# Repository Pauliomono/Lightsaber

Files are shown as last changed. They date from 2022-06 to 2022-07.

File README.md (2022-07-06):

# Lightsaber

DIY Lightsaber project completed over the summer of 2020.
 
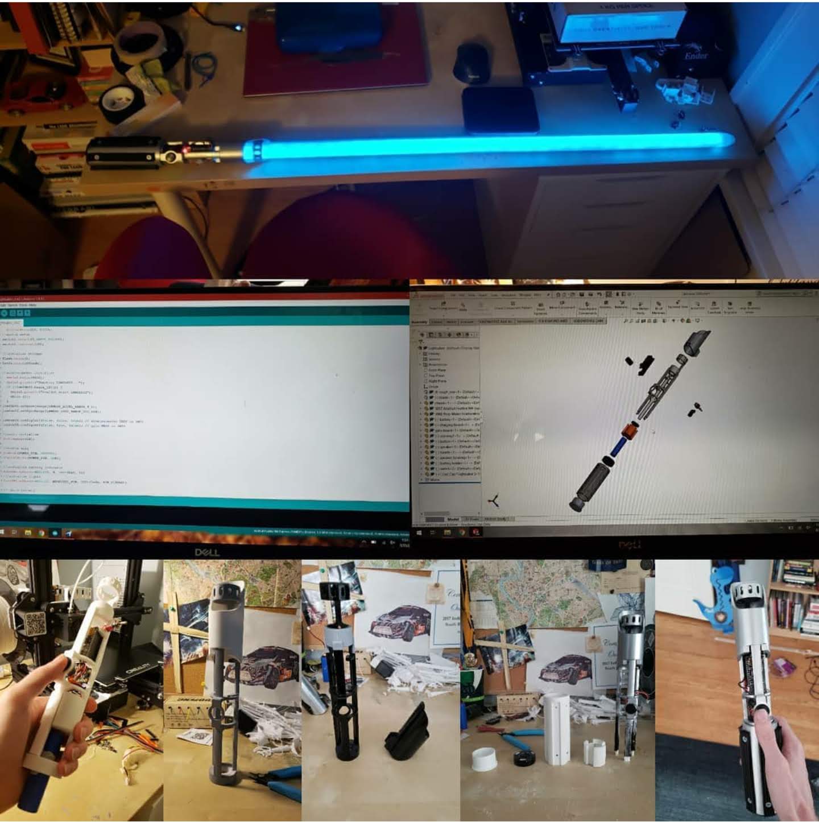
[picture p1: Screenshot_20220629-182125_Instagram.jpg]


Features include:

- Sound effects including on, off, and hit sounds
- Realistic lightsaber swing sounds mimic Doppler Effect
- LED blade with light animations for on/off sequences & reactions to hits

The entire handle is custom 3D printed and hand painted.

Electronics are handled by an Adafruit Feather M4 microcontroller with the Adafruit propshield. An MPU6050 is used for accelometer and gyroscope data. Lighting is achieved through a Neopixel strip. The lightsaber is powered by an 18650 lithium cell.

Future plans to fabricate a new handle out of aluminum and add more lighting functionality/animations.

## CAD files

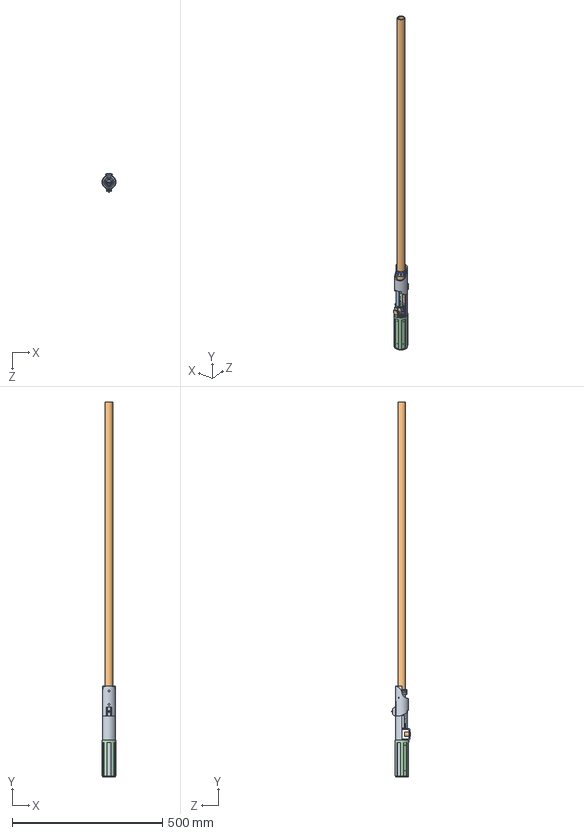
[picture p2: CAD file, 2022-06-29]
Lightsaber.SLDASM
46.7 x 1249.0 x 64.9 mm
chassis
3857 Adafruit Feather M4 Express
3988 Prop-Maker FeatherWing
battery
charging board
gyro board
opening1
button
speaker_housing
battery holder
switch
End_Cap^Lightsaber

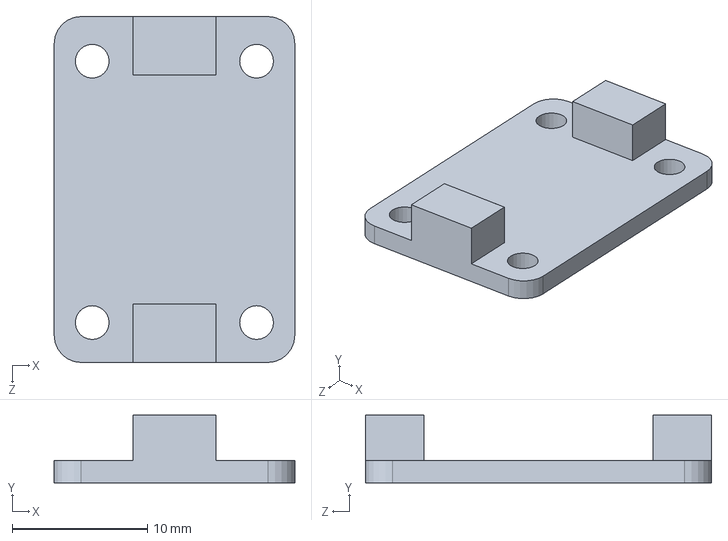
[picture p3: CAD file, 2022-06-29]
gyro board.SLDPRT
17.8 x 5.00 x 25.6 mm

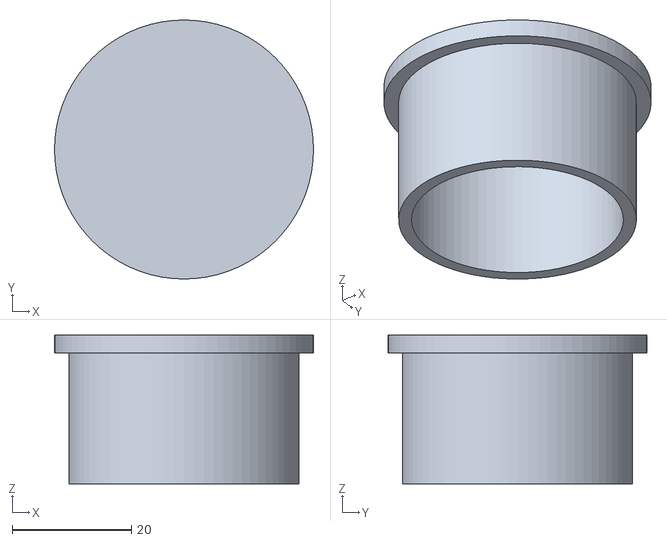
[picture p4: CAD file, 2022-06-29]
stls/End_Cap^Lightsaber.STL
43.5 x 43.5 x 25.0

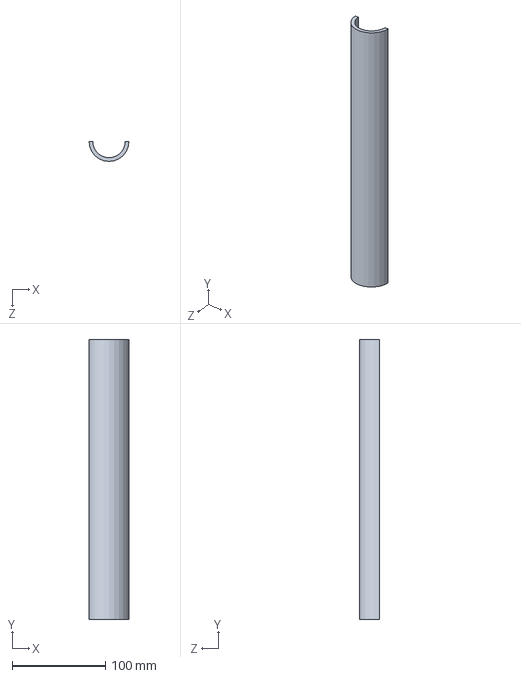
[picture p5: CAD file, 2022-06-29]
rough_size.SLDPRT
42.7 x 300.0 x 21.4 mm

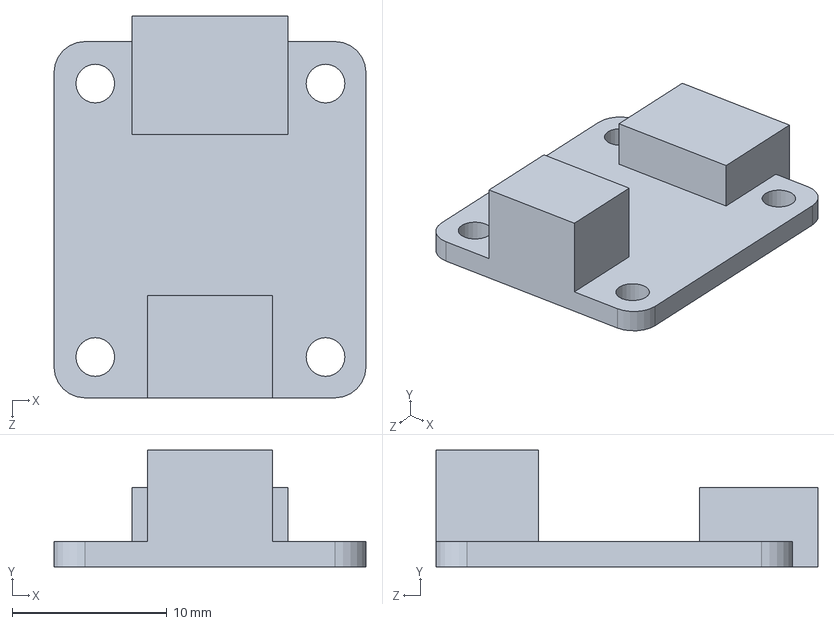
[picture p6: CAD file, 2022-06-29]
charging board.SLDPRT
20.1 x 7.55 x 24.6 mm

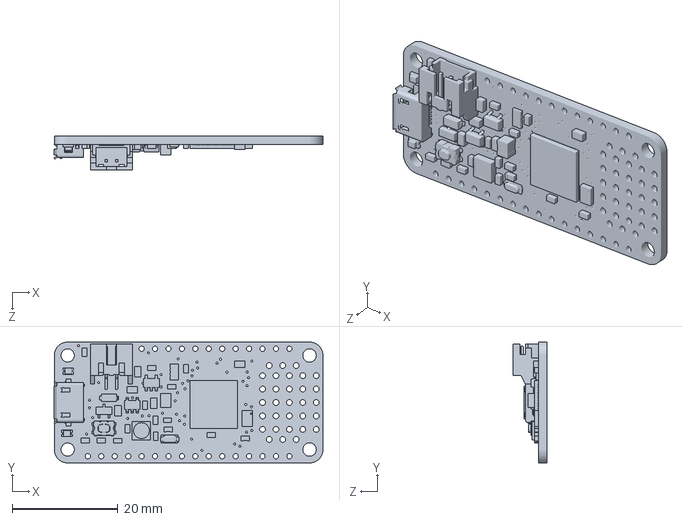
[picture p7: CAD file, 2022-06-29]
3857 Adafruit Feather M4 Express.SLDPRT
50.9 x 22.9 x 6.37 mm

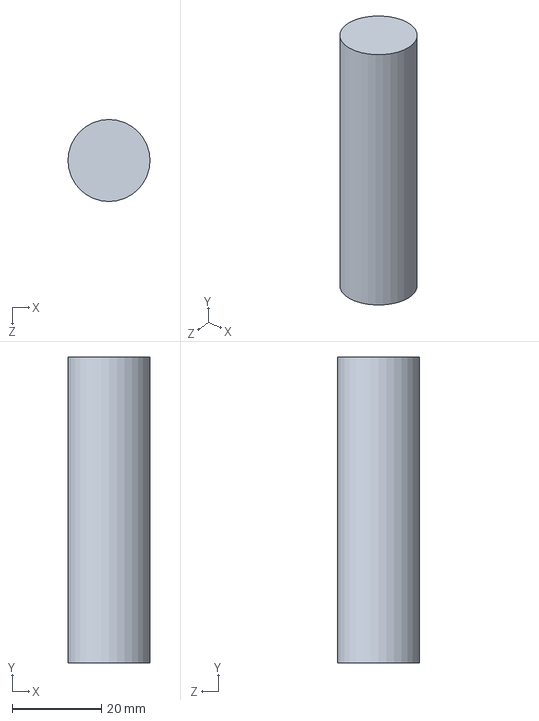
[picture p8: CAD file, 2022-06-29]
battery.SLDPRT
18.4 x 68.7 x 18.4 mm

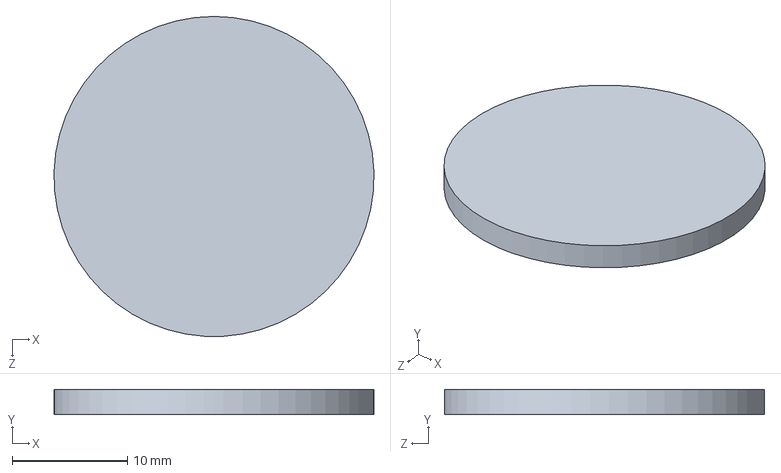
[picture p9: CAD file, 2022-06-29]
speaker.SLDPRT
27.8 x 2.20 x 27.8 mm

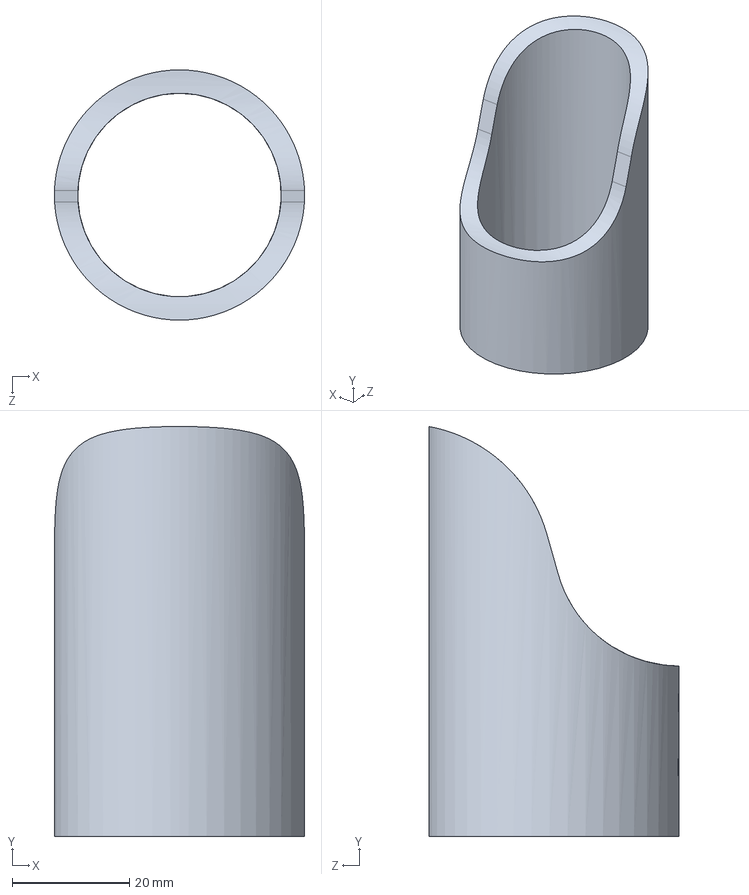
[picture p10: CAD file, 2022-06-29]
opening1.SLDPRT
42.7 x 70.0 x 42.7 mm

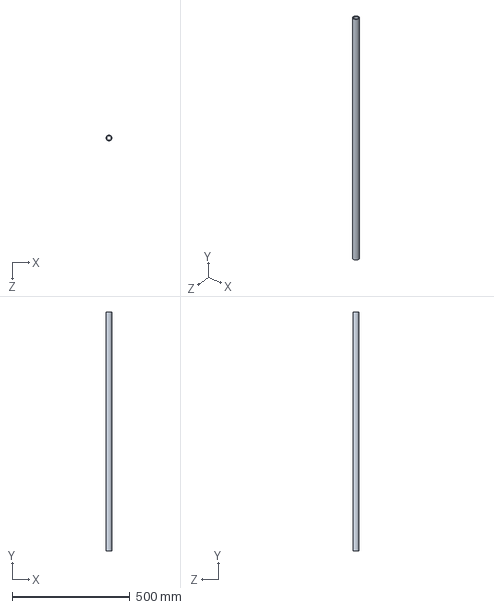
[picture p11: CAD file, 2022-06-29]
blade.SLDPRT
25.4 x 1016.0 x 25.4 mm

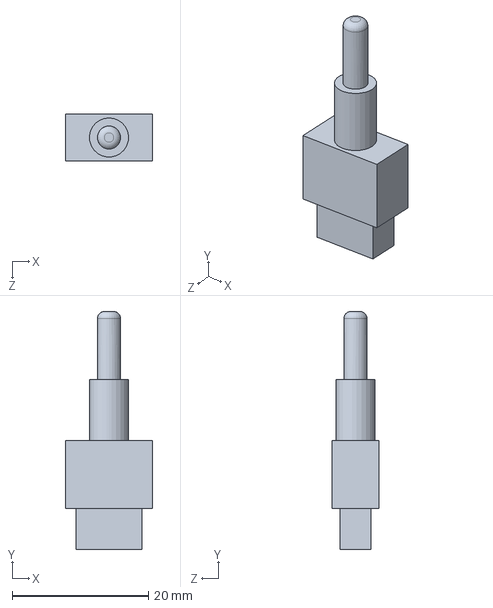
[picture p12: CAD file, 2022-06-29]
switch.SLDPRT
12.8 x 35.0 x 6.92 mm

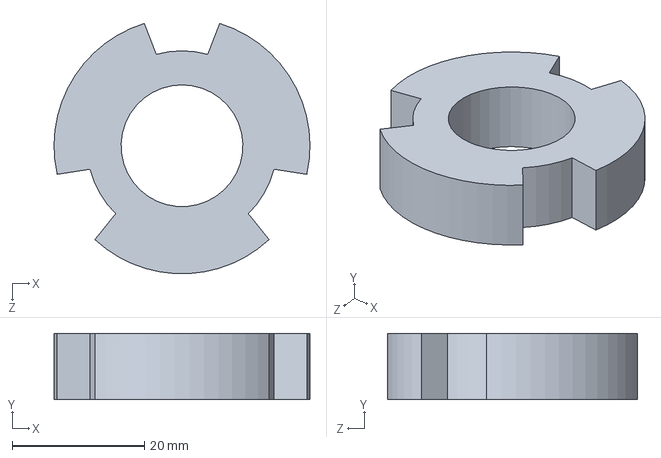
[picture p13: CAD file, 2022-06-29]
battery holder.SLDPRT
38.7 x 10.0 x 37.8 mm

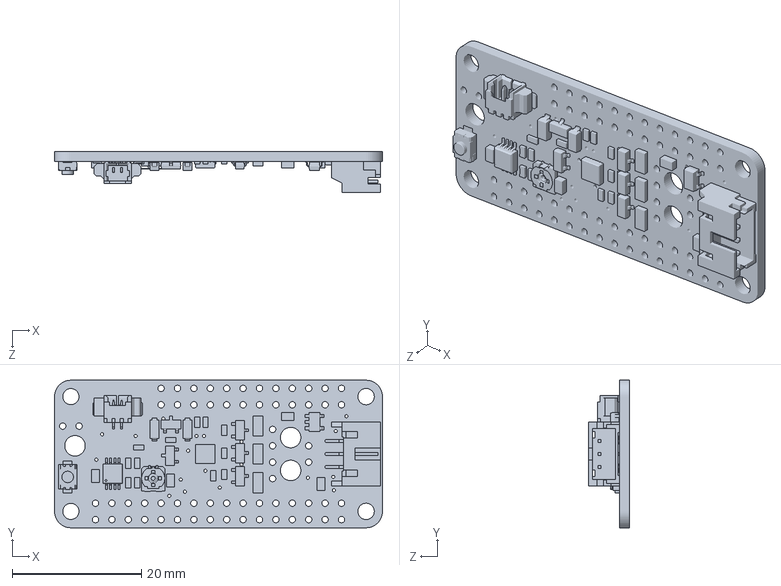
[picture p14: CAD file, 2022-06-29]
3988 Prop-Maker FeatherWing.SLDPRT
50.8 x 22.9 x 6.37 mm

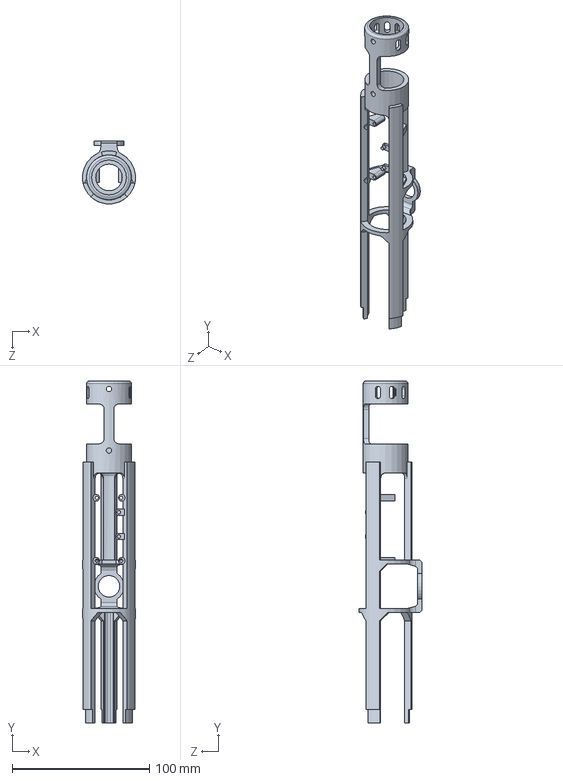
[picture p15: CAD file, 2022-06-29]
chassis.SLDPRT
38.7 x 248.9 x 45.6 mm

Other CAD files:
handle.SLDPRT
speaker_housing.SLDPRT
button.SLDPRT
3857 Adafruit Feather M4 Express.stl
3988 Prop-Maker FeatherWing.stl
stls/battery holder.STL
stls/chassis.STL
stls/handle.STL
stls/opening1.STL
stls/speaker_housing.STL

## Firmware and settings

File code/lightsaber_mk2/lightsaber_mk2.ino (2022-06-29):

#include <Adafruit_LSM6DS33.h>
#define FASTLED_ALLOW_INTERRUPTS 0
#include <FastLED.h>
#include <Audio.h>
#include <SdFat.h>
#include <Adafruit_SPIFlash.h>
#include <play_fs_wav.h>
#include <Bounce2.h>

//accel declarations
Adafruit_LSM6DS33 lsm6ds33;
#define ax accel.acceleration.x
#define ay accel.acceleration.y
#define az accel.acceleration.z
#define gx gyro.acceleration.x
#define gy gyro.acceleration.y
#define gz gyro.acceleration.z

//var declarations
float a;
float v;
float angle;
float t0 = 0;
float t1;
float dt;
int hitfx;
int pixel;
int state;
bool swt;
bool power = false;
bool hstat;
float vvol;
float avol;

//lights declarations
#define NUM_PIXELS 144
#define POWER_PIN 10
#define NEOPIXEL_PIN 5
#define swing 1
#define hit 35
#define start1 50
#define end1 100
#define start2 180
#define end2 330
CRGB leds[NUM_PIXELS];
CRGB bat[1];

//audio declarations
AudioPlayFSWav           playWav1;
AudioPlayFSWav           playWav2;
AudioPlayFSWav           playWav3;
AudioPlayFSWav           playWav4;
AudioMixer4              mixer1;
AudioOutputAnalogStereo  audioOutput;    // Dual DACs
AudioConnection          patchCord1(playWav1, 0, mixer1, 0);
AudioConnection          patchCord2(playWav2, 0, mixer1, 1);
AudioConnection          patchCord3(playWav3, 0, mixer1, 2);
AudioConnection          patchCord4(playWav4, 0, mixer1, 3);
AudioConnection          patchCord5(mixer1, 0, audioOutput, 0);

//storage declaratons
Adafruit_FlashTransport_QSPI flashTransport(PIN_QSPI_SCK, PIN_QSPI_CS, PIN_QSPI_IO0, PIN_QSPI_IO1, PIN_QSPI_IO2, PIN_QSPI_IO3);
Adafruit_SPIFlash flash(&flashTransport);
FatFileSystem fatfs;

//switch
Bounce switch1 = Bounce();

void setup() {

  pinMode(13, OUTPUT);
  digitalWrite(13, HIGH);
//switch setup
switch1.attach(9,INPUT_PULLUP);
switch1.interval(10); 
 
//initialize storage
flash.begin();
fatfs.begin(&flash);

//accelerometer initialize
  Serial.begin(9600);
  Serial.println("Starting LSM6DS33...");
  if (!lsm6ds33.begin_I2C()) { 
    Serial.println("Couldnt start LSM6DS33");
    while (1);
  }
lsm6ds33.setAccelRange(LSM6DS_ACCEL_RANGE_4_G);
lsm6ds33.setGyroRange(LSM6DS_GYRO_RANGE_500_DPS);

lsm6ds33.configInt1(false, false, true); // accelerometer DRDY on INT1
lsm6ds33.configInt2(false, true, false); // gyro DRDY on INT2

//audio initialize
AudioMemory(64);

//enable wing
pinMode(POWER_PIN, OUTPUT);
digitalWrite(POWER_PIN, LOW);

//initialize battery indicator
FastLED.addLeds<WS2812B, 8, GRB>(bat, 1);
//initialize lights
FastLED.addLeds<WS2812B, NEOPIXEL_PIN, GRB>(leds, NUM_PIXELS);

// check battery
battery();
}

//battery lvl function
void battery()
{
  float voltage = analogRead(A6);
  voltage *= 6.6;
  voltage /= 1024;
  Serial.println(voltage);
  if (voltage > 3.8){
    bat[0] = CRGB(7, 0, 7);
    FastLED.show();
  }
  else if (voltage > 3.73){
    bat[0] = CRGB(15, 7, 0);
    FastLED.show();
  }
  else {
    bat[0] = CRGB(15, 0, 0);
    FastLED.show();
  }
}

//sound function main hum
void playBase()
{
  File f;
  f = fatfs.open("idle.wav");
  playWav1.play(f);
}

//sound function for pitched up swing
void playH()
{
  File f;
  f = fatfs.open("high.wav");
  playWav2.play(f);
}

//sound function for pitched down swing
void playL()
{
  File f;
  f = fatfs.open("low.wav");
  playWav3.play(f);
}

//sound function for effects
void playFx(const char *filename)
{
  File f;
  f = fatfs.open(filename);
  playWav4.play(f);
}

//hit light animations
void burst(CRGB leds[]){
  fill_solid( &(leds[0]), NUM_PIXELS, CRGB( 63, 127, 127));
  FastLED.show();
  delay(100);
  fill_solid( &(leds[0]), NUM_PIXELS, CRGB(0, 45, 60));
  FastLED.show();
}

//on function
void on(CRGB leds[]){
  float vol;
  power = true;
  digitalWrite(POWER_PIN, HIGH);
  FastLED.clear();
  FastLED.show();
  mixer1.gain(3, .5);
  playFx("on.wav");
  playBase();
  for (int i=0; i < NUM_PIXELS; i = i + 4){
  leds[i]= CRGB(0, 15, 20);
  leds[i+1]= CRGB(0, 45, 60);
  leds[i+2]= CRGB(0, 45, 60);
  leds[i+3]= CRGB(0, 45, 60);
  vol = sq(i);
  mixer1.gain(0, vol/20736);  
  delay(20);
  FastLED.show();
  }
  while (playWav4.isPlaying()){}  
  while (swt){
    switch1.update();
    swt = !switch1.read();
  }
}

//off function
void off(CRGB leds[]){
  float vol;
  power = false;
  mixer1.gain(3, .5);
  playFx("off.wav");
  for (int i=NUM_PIXELS; i > 0; i = i - 4){
  leds[i]= CRGB(0, 0, 0);
  leds[i+1]= CRGB(0, 0, 0);
  leds[i+2]= CRGB(0, 0, 0);
  leds[i+3]= CRGB(0, 0, 0);
  if (playWav1.isPlaying() == false) {
    playBase();
  }
  vol = sq(i);
  mixer1.gain(0, vol/20736);
  delay(30);
  FastLED.show();
  }
  playWav1.stop();
  FastLED.clear();
  FastLED.show();
  while (swt){
      switch1.update();
      swt = !switch1.read();
    }
  while (playWav4.isPlaying()){}
  digitalWrite(POWER_PIN, LOW);
  battery();
}

//main code
void loop() {
switch1.update();
swt = !switch1.read();
if(swt){
  on(leds);
}
  while(power){
  switch1.update();
  swt = !switch1.read();
  if(swt){
    off(leds);
  }
    sensors_event_t accel;
    sensors_event_t gyro;
    sensors_event_t temp; 
    lsm6ds33.getEvent(&accel, &gyro, &temp);
    t0 = t1;
    t1 = millis();
    dt = t1 - t0;
  if (playWav1.isPlaying() == false) {
    playBase();
  }
    v = sqrt(sq(gy)+sq(gz));
    angle = angle + v * dt/1000*180/3.14;
    if (angle >= 360) {
      angle = angle - 360;
    }
    a = sqrt(sq(ax)+sq(ay)+sq(az));
    
    vvol = v/7;
    if (angle < 180) {
      avol = (angle - 50)/50;
    }
    else if (angle >=180){
      avol = (angle - 180)/150;
    }
    Serial.print("\ta: "); Serial.print(a);
    Serial.print("\tv: "); Serial.print(v);
    Serial.print("\tangle: "); Serial.print(angle);
    Serial.print("\tavol: "); Serial.print(avol);
    Serial.print("\tvvol: "); Serial.print(vvol);
    Serial.print("\tvdt: "); Serial.println(dt);
    if (a > hit && v > swing && playWav4.isPlaying() == false){
      hitfx = random(0, 3);
      mixer1.gain(3, 1);
      if (hitfx == 0){
        playFx("hit1.wav");
      }
      if (hitfx == 1){
        playFx("hit2.wav");
      }
      if (hitfx == 2){
        playFx("hit3.wav");
      }
      burst(leds); 
    }
  if (v > swing){
    if (angle < start1) {
      if (playWav2.isPlaying() == false) {
        playH();
      }
      mixer1.gain(1, vvol);
      mixer1.gain(2, 0);
    }
    else if (angle >=start1 && angle <end1) {
      if (playWav2.isPlaying() == false) {
        playH();
      }
      if (playWav3.isPlaying() == false) {
        playL();
      }
      mixer1.gain(2, avol*vvol);  
      mixer1.gain(1, (1 - avol)*vvol);
    }
    else if (angle >= end1 && angle < start2) {
      if (playWav3.isPlaying() == false) {
        playL();
      }
      mixer1.gain(2, vvol);
      mixer1.gain(1, 0); 
    }
    else if (angle >= start2 && angle < end2) { 
      if (playWav2.isPlaying() == false) {
        playH();
      }
      if (playWav3.isPlaying() == false) {
        playL();
      }
      mixer1.gain(2, (1 - avol)*vvol);  
      mixer1.gain(1, avol*vvol);
    }
    else if (angle >= end2) {
      if (playWav2.isPlaying() == false) {
        playH();
      }
      mixer1.gain(1, vvol);      
      mixer1.gain(2, 0);
    }
    mixer1.gain(0, 1 - vvol);
    }
    else {
      playWav2.stop();
      playWav3.stop();
      angle = 0;
    }
  }
}
